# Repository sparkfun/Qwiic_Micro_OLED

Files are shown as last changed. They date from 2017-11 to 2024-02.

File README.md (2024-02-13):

SparkFun SparkFun Micro OLED Breakout (Qwiic)
========================================

SparkFun Micro OLED Breakout (Qwiic) (https://www.sparkfun.com/products/22495)

[*SparkFun Micro OLED Breakout (Qwiic) (LCD-22495)*](https://www.sparkfun.com/products/22495)

The SparkFun Qwiic Micro OLED Breakout is a Qwiic-enabled version of our popular Micro OLED display! The small monochrome, blue-on-black OLED screen presents incredibly clear images for your viewing pleasure. 

Repository Contents
-------------------

* **/Hardware** - Eagle design files (.brd, .sch)
* **/Libraries** - Libraries for use with the SparkFun Micro OLED Breakout (Qwiic)
* **/Production** - Production panel files (.brd)
* **/Software** - Related software for the SparkFun Micro OLED Breakout (Qwiic).

Documentation
--------------
* **[Micro OLED Breakout Library](https://github.com/sparkfun/SparkFun_Micro_OLED_Arduino_Library)** - Latest Arduino library for the Micro OLED Breakout.
* **[Qwiic Micro OLED Breakout Library](https://github.com/sparkfun/SparkFun_Qwiic_OLED_Arduino_Library)** - Alternative Arduino library for the Qwiic Micro OLED Breakout. This library is higher performance and handles memory better than the Micro OLED Arduino Library. This library also works with 2x other Qwiic OLEDs!!!
* **[SparkFun Fritzing Part](https://github.com/sparkfun/Fritzing_Parts/blob/main/products/22495_sfe_qwiic_micro_oled_breakout_top_view.fzpz)** - V11, top view
* **[SparkFun Fritzing Part](https://github.com/sparkfun/Fritzing_Parts/blob/main/products/14532_sfe_Qwiic_OLED_Breakout.fzpz)** - V10, bottom view
* **[Hookup Guide](https://learn.sparkfun.com/tutorials/qwiic-micro-oled-hookup-guide)** - Basic hookup guide for the SparkFun Micro OLED Breakout (Qwiic).

Product Versions
----------------
* [LCD-22495](https://www.sparkfun.com/products/22495) - SparkFun Qwiic Micro OLED Breakout, v11
* [LCD-14532](https://www.sparkfun.com/products/14532) - SparkFun Qwiic Micro OLED Breakout, v10
* [SPX-14269 (RETIRED)](https://www.sparkfun.com/products/14269) - SparkX Qwiic Micro OLED Breakout

License Information
-------------------

This product is _**open source**_! 

Please review the LICENSE.md file for license information. 

If you have any questions or concerns on licensing, please contact techsupport@sparkfun.com.

Distributed as-is; no warranty is given.

- Your friends at SparkFun.

_<COLLABORATION CREDIT>_

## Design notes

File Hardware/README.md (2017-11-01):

SparkFun <PRODUCT NAME> Design Files
=====================================

The .sch and .brd files hare are Eagle CAD schematic and PCB design files from SparkFun Electronics.
A freeware version of Eagle can be found [here](http://www.cadsoftusa.com/download-eagle/freeware/).

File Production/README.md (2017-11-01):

SparkFun <PRODUCT NAME> Production Files
=========================================

These are the production files SparkFun uses for printing PCBs.

License Information
-------------------
This product is open source! 

The hardware is released under [Creative Commons ShareAlike 4.0 International](https://creativecommons.org/licenses/by-sa/4.0/).

Please use, reuse, and modify these files as you see fit. Please maintain attribution to SparkFun Electronics and release anything derivative under the same license.

Distributed as-is; no warranty is given.

- Your friends at SparkFun.

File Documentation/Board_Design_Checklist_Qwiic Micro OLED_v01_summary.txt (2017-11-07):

1) Does this board adhere to the standard manufacturing process? (Kitting time, glue curing, humidor time, etc.) [NO]
comment: hot bar for screen

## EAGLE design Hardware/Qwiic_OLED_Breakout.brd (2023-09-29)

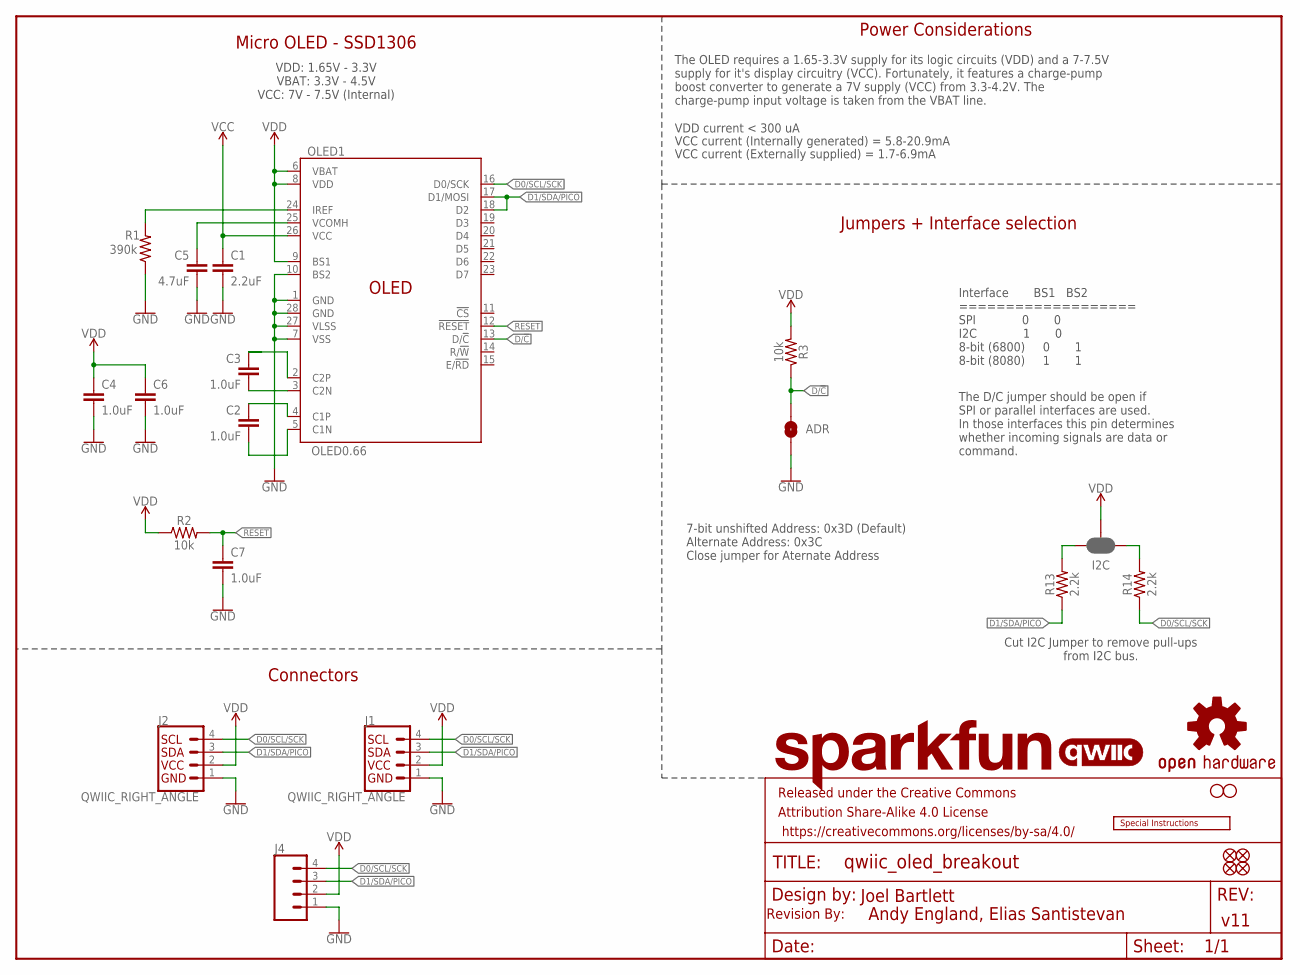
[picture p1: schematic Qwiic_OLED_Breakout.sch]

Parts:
ADR: JUMPER-SMT_2_NO_SILK; SMT-JUMPER_2_NO_SILK
C1: 2.2uF; 0805
C2, C3: 1.0uF; 0805
C4, C6, C7: 1.0uF; 0603
C5: 4.7uF; 1206
FID1, FID2, FID3, FID4: FIDUCIAL1X2; FIDUCIAL-1X2
FRAME1: FRAME-LETTER; CREATIVE_COMMONS
H1, H2: STAND-OFF
I2C: JUMPER-SMT_3_2-NC_PASTE_SILK; SMT-JUMPER_3_2-NC_PASTE_SILK
J1, J2: QWIIC_RIGHT_ANGLE; JST04_1MM_RA
J4: CONN_041X04_NO_SILK_NO_POP; 1X04_NO_SILK
LOGO2: SFE_LOGO_NAME.1_INCH; SFE_LOGO_NAME_.1
LOGO3: OSHW-LOGOS; OSHW-LOGO-S
LOGO5: QWIIC_LOGO_4MM; QWIIC_4MM
LOGO6: SPECIAL_INSTRUCTIONS-ORDERING; ORDERING_INSTRUCTIONS
OLED1: OLED0.66; OLED-0.66-64X48
R1: 390k; 0603
R2, R3: 10k; 0603
R13, R14: 2.2k; 0603

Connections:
C1P: C2.1, OLED1.4 (C1P)
C2N: C3.2, OLED1.3 (C2N)
D0/SCL/SCK: J1.4, J2.4, J4.4, OLED1.16 (D0/SCK), R14.1
D1/SDA/PICO: J1.3, J2.3, J4.3, OLED1.17 (D1/MOSI), OLED1.18 (D2), R13.1
D/!C!: ADR.2, OLED1.13 (D/!C!), R3.1
GND: ADR.1, C1.2, C4.2, C5.2, C6.2, C7.2, J1.1, J2.1, J4.1, OLED1.1 (GND), OLED1.7 (VSS), OLED1.10 (BS2), OLED1.27 (VLSS), OLED1.28 (GND), R1.1
IREF: OLED1.24 (IREF), R1.2
unnamed: C3.1, OLED1.2 (C2P)
unnamed: C2.2, OLED1.5 (C1N)
unnamed: I2C.3, R13.2
unnamed: I2C.1, R14.2
RESET: C7.1, OLED1.12 (!RESET!), R2.2
VCC: C1.1, OLED1.26 (VCC)
VCOMH: C5.1, OLED1.25 (VCOMH)
VDD: C4.1, C6.1, I2C.2, J1.2, J2.2, J4.2, OLED1.6 (VBAT), OLED1.8 (VDD), OLED1.9 (BS1), R2.1, R3.2

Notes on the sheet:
v11
VDD: 1.65V - 3.3V VBAT: 3.3V - 4.5V VCC: 7V - 7.5V (Internal)
VDD current < 300 uA
VCC current (Internally generated) = 5.8-20.9mA
VCC current (Externally supplied) = 1.7-6.9mA
Interface BS1 BS2 =================== SPI 0 0 I2C 1 0 8-bit (6800) 0 1 8-bit (8080) 1 1
Jumpers + Interface selection
7-bit unshifted Address: 0x3D (Default) Alternate Address: 0x3C Close jumper for Aternate Address
Power Considerations
The OLED requires a 1.65-3.3V supply for its logic circuits (VDD) and a 7-7.5V supply for it's display circuitry (VCC). Fortunately, it features a charge-pump boost converter to generate a 7V supply (VCC) from 3.3-4.2V. The charge-pump input voltage is taken from the VBAT line.
The D/C jumper should be open if SPI or parallel interfaces are used. In those interfaces this pin determines whether incoming signals are data or command.
Cut I2C Jumper to remove pull-ups from I2C bus.
Joel Bartlett
Andy England, Elias Santistevan
Connectors
Micro OLED - SSD1306
Revision By:

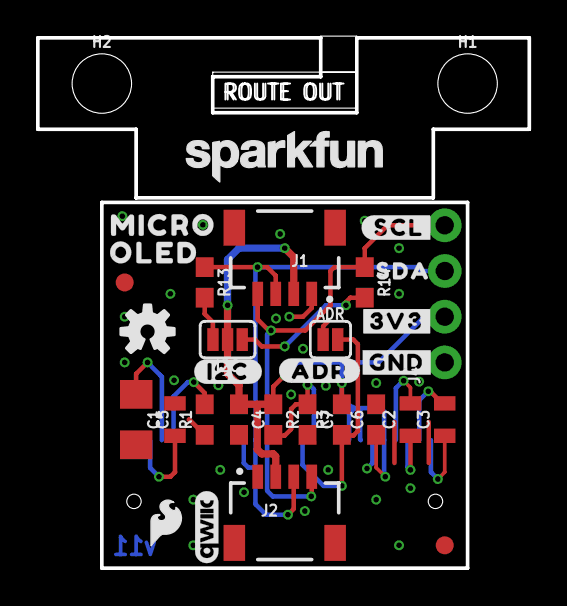
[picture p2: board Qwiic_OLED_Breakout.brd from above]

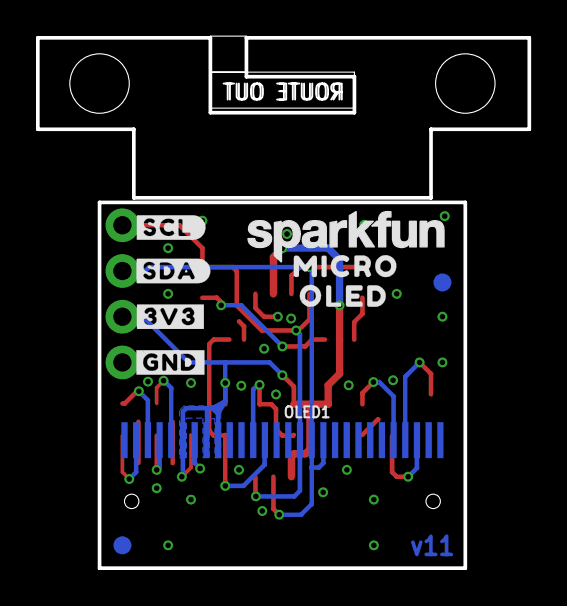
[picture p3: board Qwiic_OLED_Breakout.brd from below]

Board: 2 copper layers, 27.3 x 29.6 mm, 45 parts (10 on the bottom side), 15 nets.

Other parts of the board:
LOGO4: SFE_LOGO_NAME.1_INCH; SFE_LOGO_NAME_.1
U$1, U$13: MICRO593420
U$2, U$14: OLED593421
U$3: #ADR#5
U$4: #SCL#9
U$5, U$11: #3V3#1
U$6, U$12: #GND#0
U$7: SDA8
U$8: #I2C#1348
U$9: #SCL#8
U$10: #SDA#10
U$15: SFE_LOGO_FLAME_.1

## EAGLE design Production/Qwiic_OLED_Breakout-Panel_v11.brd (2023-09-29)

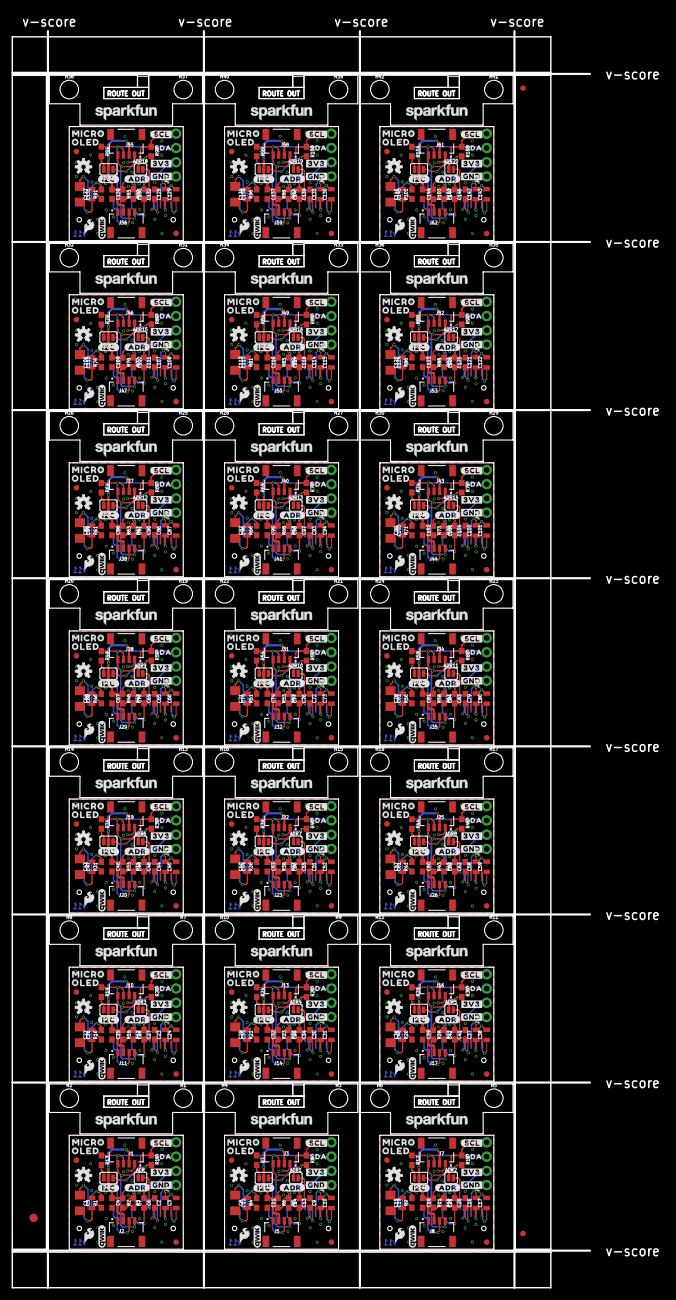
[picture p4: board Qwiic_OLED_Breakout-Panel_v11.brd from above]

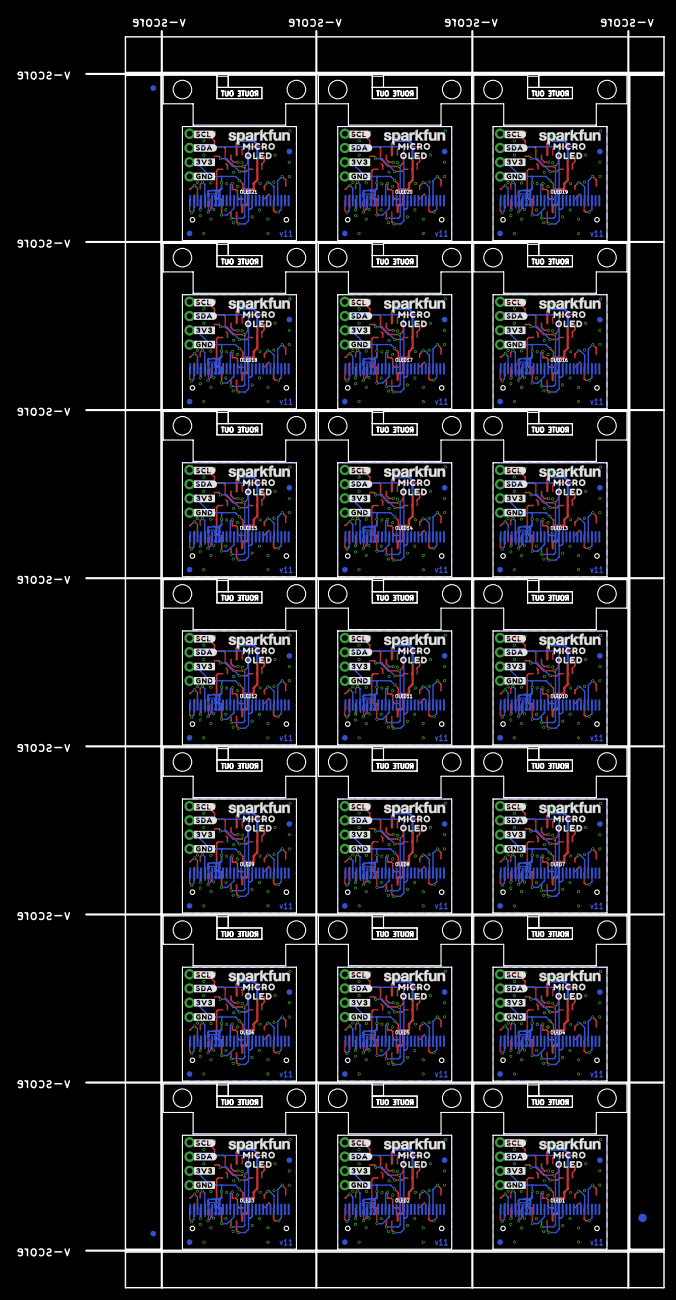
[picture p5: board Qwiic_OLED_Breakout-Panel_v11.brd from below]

Board: 2 copper layers, 103.0 x 224.0 mm, 909 parts (213 on the bottom side), 315 nets.

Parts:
ADR, ADR1, ADR2, ADR3, ADR4, ADR5, ADR6, ADR7, ADR8, ADR9, ADR10, ADR11, ADR12, ADR13, ADR14, ADR15, ADR16, ADR17, ADR18, ADR19, ADR20: JUMPER-SMT_2_NO_SILK; SMT-JUMPER_2_NO_SILK
C1, C8, C15, C22, C29, C36, C43, C50, C57, C64, C71, C78, C85, C92, C99, C106, C113, C120, C127, C134, C141: 2.2uF; 0805
C2, C3, C9, C10, C16, C17, C23, C24, C30, C31, C37, C38, C44, C45, C51, C52, C58, C59, C65, C66, C72, C73, C79, C80, C86, C87, C93, C94, C100, C101, C107, C108, C114, C115, C121, C122, C128, C129, C135, C136, C142, C143: 1.0uF; 0805
C4, C6, C7, C11, C13, C14, C18, C20, C21, C25, C27, C28, C32, C34, C35, C39, C41, C42, C46, C48, C49, C53, C55, C56, C60, C62, C63, C67, C69, C70, C74, C76, C77, C81, C83, C84, C88, C90, C91, C95, C97, C98, C102, C104, C105, C109, C111, C112, C116, C118, C119, C123, C125, C126, C130, C132, C133, C137, C139, C140, C144, C146, C147: 1.0uF; 0603
C5, C12, C19, C26, C33, C40, C47, C54, C61, C68, C75, C82, C89, C96, C103, C110, C117, C124, C131, C138, C145: 4.7uF; 1206
E$1, E$2, E$3, E$4: FIDUCIAL-1X2
E$5, E$6: FIDUCIAL-1.5X3
FID1, FID2, FID3, FID4, FID5, FID6, FID7, FID8, FID9, FID10, FID11, FID12, FID13, FID14, FID15, FID16, FID17, FID18, FID19, FID20, FID21, FID22, FID23, FID24, FID25, FID26, FID27, FID28, FID29, FID30, FID31, FID32, FID33, FID34, FID35, FID36, FID37, FID38, FID39, FID40, FID41, FID42, FID43, FID44, FID45, FID46, FID47, FID48, FID49, FID50, FID51, FID52, FID53, FID54, FID55, FID56, FID57, FID58, FID59, FID60, FID61, FID62, FID63, FID64, FID65, FID66, FID67, FID68, FID69, FID70, FID71, FID72, FID73, FID74, FID75, FID76, FID77, FID78, FID79, FID80, FID81, FID82, FID83, FID84: FIDUCIAL1X2; FIDUCIAL-1X2
H1, H2, H3, H4, H5, H6, H7, H8, H9, H10, H11, H12, H13, H14, H15, H16, H17, H18, H19, H20, H21, H22, H23, H24, H25, H26, H27, H28, H29, H30, H31, H32, H33, H34, H35, H36, H37, H38, H39, H40, H41, H42: STAND-OFF
I2C, I2C1, I2C2, I2C3, I2C4, I2C5, I2C6, I2C7, I2C8, I2C9, I2C10, I2C11, I2C12, I2C13, I2C14, I2C15, I2C16, I2C17, I2C18, I2C19, I2C20: JUMPER-SMT_3_2-NC_PASTE_SILK; SMT-JUMPER_3_2-NC_PASTE_SILK
J1, J2, J3, J5, J7, J8, J10, J11, J13, J14, J16, J17, J19, J20, J22, J23, J25, J26, J28, J29, J31, J32, J34, J35, J37, J38, J40, J41, J43, J44, J46, J47, J49, J50, J52, J53, J55, J56, J58, J59, J61, J62: QWIIC_RIGHT_ANGLE; JST04_1MM_RA
J4, J6, J9, J12, J15, J18, J21, J24, J27, J30, J33, J36, J39, J42, J45, J48, J51, J54, J57, J60, J63: 1X04_NO_SILK
LOGO1, LOGO3, LOGO9, LOGO13, LOGO17, LOGO21, LOGO25, LOGO29, LOGO33, LOGO37, LOGO41, LOGO45, LOGO49, LOGO53, LOGO57, LOGO61, LOGO65, LOGO69, LOGO73, LOGO77, LOGO81: OSHW-LOGOS; OSHW-LOGO-S
LOGO2, LOGO4, LOGO7, LOGO8, LOGO11, LOGO12, LOGO15, LOGO16, LOGO19, LOGO20, LOGO23, LOGO24, LOGO27, LOGO28, LOGO31, LOGO32, LOGO35, LOGO36, LOGO39, LOGO40, LOGO43, LOGO44, LOGO47, LOGO48, LOGO51, LOGO52, LOGO55, LOGO56, LOGO59, LOGO60, LOGO63, LOGO64, LOGO67, LOGO68, LOGO71, LOGO72, LOGO75, LOGO76, LOGO79, LOGO80, LOGO83, LOGO84: SFE_LOGO_NAME.1_INCH; SFE_LOGO_NAME_.1
LOGO5, LOGO6, LOGO10, LOGO14, LOGO18, LOGO22, LOGO26, LOGO30, LOGO34, LOGO38, LOGO42, LOGO46, LOGO50, LOGO54, LOGO58, LOGO62, LOGO66, LOGO70, LOGO74, LOGO78, LOGO82: QWIIC_LOGO_4MM; QWIIC_4MM
OLED1, OLED2, OLED3, OLED4, OLED5, OLED6, OLED7, OLED8, OLED9, OLED10, OLED11, OLED12, OLED13, OLED14, OLED15, OLED16, OLED17, OLED18, OLED19, OLED20, OLED21: OLED0.66; OLED-0.66-64X48
R1, R4, R9, R16, R21, R26, R31, R36, R41, R46, R51, R56, R61, R66, R71, R76, R81, R86, R91, R96, R101: 390k; 0603
R2, R3, R5, R6, R10, R11, R17, R18, R22, R23, R27, R28, R32, R33, R37, R38, R42, R43, R47, R48, R52, R53, R57, R58, R62, R63, R67, R68, R72, R73, R77, R78, R82, R83, R87, R88, R92, R93, R97, R98, R102, R103: 10k; 0603
R7, R8, R12, R13, R14, R15, R19, R20, R24, R25, R29, R30, R34, R35, R39, R40, R44, R45, R49, R50, R54, R55, R59, R60, R64, R65, R69, R70, R74, R75, R79, R80, R84, R85, R89, R90, R94, R95, R99, R100, R104, R105: 2.2k; 0603
U$1, U$13, U$16, U$28, U$31, U$43, U$46, U$58, U$61, U$73, U$76, U$88, U$91, U$103, U$106, U$118, U$121, U$133, U$136, U$148, U$151, U$163, U$166, U$178, U$181, U$193, U$196, U$208, U$211, U$223, U$226, U$238, U$241, U$253, U$256, U$268, U$271, U$283, U$286, U$298, U$301, U$313: MICRO593420
U$2, U$14, U$17, U$29, U$32, U$44, U$47, U$59, U$62, U$74, U$77, U$89, U$92, U$104, U$107, U$119, U$122, U$134, U$137, U$149, U$152, U$164, U$167, U$179, U$182, U$194, U$197, U$209, U$212, U$224, U$227, U$239, U$242, U$254, U$257, U$269, U$272, U$284, U$287, U$299, U$302, U$314: OLED593421
U$3, U$18, U$33, U$48, U$63, U$78, U$93, U$108, U$123, U$138, U$153, U$168, U$183, U$198, U$213, U$228, U$243, U$258, U$273, U$288, U$303: #ADR#5
U$4, U$19, U$34, U$49, U$64, U$79, U$94, U$109, U$124, U$139, U$154, U$169, U$184, U$199, U$214, U$229, U$244, U$259, U$274, U$289, U$304: #SCL#9
U$5, U$11, U$20, U$26, U$35, U$41, U$50, U$56, U$65, U$71, U$80, U$86, U$95, U$101, U$110, U$116, U$125, U$131, U$140, U$146, U$155, U$161, U$170, U$176, U$185, U$191, U$200, U$206, U$215, U$221, U$230, U$236, U$245, U$251, U$260, U$266, U$275, U$281, U$290, U$296, U$305, U$311: #3V3#1
U$6, U$12, U$21, U$27, U$36, U$42, U$51, U$57, U$66, U$72, U$81, U$87, U$96, U$102, U$111, U$117, U$126, U$132, U$141, U$147, U$156, U$162, U$171, U$177, U$186, U$192, U$201, U$207, U$216, U$222, U$231, U$237, U$246, U$252, U$261, U$267, U$276, U$282, U$291, U$297, U$306, U$312: #GND#0
U$7, U$22, U$37, U$52, U$67, U$82, U$97, U$112, U$127, U$142, U$157, U$172, U$187, U$202, U$217, U$232, U$247, U$262, U$277, U$292, U$307: SDA8
U$8, U$23, U$38, U$53, U$68, U$83, U$98, U$113, U$128, U$143, U$158, U$173, U$188, U$203, U$218, U$233, U$248, U$263, U$278, U$293, U$308: #I2C#1348
U$9, U$24, U$39, U$54, U$69, U$84, U$99, U$114, U$129, U$144, U$159, U$174, U$189, U$204, U$219, U$234, U$249, U$264, U$279, U$294, U$309: #SCL#8
U$10, U$25, U$40, U$55, U$70, U$85, U$100, U$115, U$130, U$145, U$160, U$175, U$190, U$205, U$220, U$235, U$250, U$265, U$280, U$295, U$310: #SDA#10
U$15, U$30, U$45, U$60, U$75, U$90, U$105, U$120, U$135, U$150, U$165, U$180, U$195, U$210, U$225, U$240, U$255, U$270, U$285, U$300, U$315: SFE_LOGO_FLAME_.1

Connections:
C1P: C2.1, OLED1.4
C1P1: C9.1, OLED2.4
C1P2: C16.1, OLED3.4
C1P3: C23.1, OLED4.4
C1P4: C30.1, OLED5.4
C1P5: C37.1, OLED6.4
C1P6: C44.1, OLED7.4
C1P7: C51.1, OLED8.4
C1P8: C58.1, OLED9.4
C1P9: C65.1, OLED10.4
C1P10: C72.1, OLED11.4
C1P11: C79.1, OLED12.4
C1P12: C86.1, OLED13.4
C1P13: C93.1, OLED14.4
C1P14: C100.1, OLED15.4
C1P15: C107.1, OLED16.4
C1P16: C114.1, OLED17.4
C1P17: C121.1, OLED18.4
C1P18: C128.1, OLED19.4
C1P19: C135.1, OLED20.4
C1P20: C142.1, OLED21.4
C2N: C3.2, OLED1.3
C2N1: C10.2, OLED2.3
C2N2: C17.2, OLED3.3
C2N3: C24.2, OLED4.3
C2N4: C31.2, OLED5.3
C2N5: C38.2, OLED6.3
C2N6: C45.2, OLED7.3
C2N7: C52.2, OLED8.3
C2N8: C59.2, OLED9.3
C2N9: C66.2, OLED10.3
C2N10: C73.2, OLED11.3
C2N11: C80.2, OLED12.3
C2N12: C87.2, OLED13.3
C2N13: C94.2, OLED14.3
C2N14: C101.2, OLED15.3
C2N15: C108.2, OLED16.3
C2N16: C115.2, OLED17.3
C2N17: C122.2, OLED18.3
C2N18: C129.2, OLED19.3
C2N19: C136.2, OLED20.3
C2N20: C143.2, OLED21.3
D0/SCL/SCK: J1.4, J2.4, J4.4, OLED1.16, R14.1
D0/SCL/SCK1: J3.4, J5.4, J6.4, OLED2.16, R8.1
D0/SCL/SCK2: J7.4, J8.4, J9.4, OLED3.16, R15.1
D0/SCL/SCK3: J10.4, J11.4, J12.4, OLED4.16, R20.1
D0/SCL/SCK4: J13.4, J14.4, J15.4, OLED5.16, R25.1
D0/SCL/SCK5: J16.4, J17.4, J18.4, OLED6.16, R30.1
D0/SCL/SCK6: J19.4, J20.4, J21.4, OLED7.16, R35.1
D0/SCL/SCK7: J22.4, J23.4, J24.4, OLED8.16, R40.1
D0/SCL/SCK8: J25.4, J26.4, J27.4, OLED9.16, R45.1
D0/SCL/SCK9: J28.4, J29.4, J30.4, OLED10.16, R50.1
D0/SCL/SCK10: J31.4, J32.4, J33.4, OLED11.16, R55.1
D0/SCL/SCK11: J34.4, J35.4, J36.4, OLED12.16, R60.1
D0/SCL/SCK12: J37.4, J38.4, J39.4, OLED13.16, R65.1
D0/SCL/SCK13: J40.4, J41.4, J42.4, OLED14.16, R70.1
D0/SCL/SCK14: J43.4, J44.4, J45.4, OLED15.16, R75.1
D0/SCL/SCK15: J46.4, J47.4, J48.4, OLED16.16, R80.1
D0/SCL/SCK16: J49.4, J50.4, J51.4, OLED17.16, R85.1
D0/SCL/SCK17: J52.4, J53.4, J54.4, OLED18.16, R90.1
D0/SCL/SCK18: J55.4, J56.4, J57.4, OLED19.16, R95.1
D0/SCL/SCK19: J58.4, J59.4, J60.4, OLED20.16, R100.1
D0/SCL/SCK20: J61.4, J62.4, J63.4, OLED21.16, R105.1
D1/SDA/PICO: J1.3, J2.3, J4.3, OLED1.17, OLED1.18, R13.1
D1/SDA/PICO1: J3.3, J5.3, J6.3, OLED2.17, OLED2.18, R7.1
D1/SDA/PICO2: J7.3, J8.3, J9.3, OLED3.17, OLED3.18, R12.1
D1/SDA/PICO3: J10.3, J11.3, J12.3, OLED4.17, OLED4.18, R19.1
D1/SDA/PICO4: J13.3, J14.3, J15.3, OLED5.17, OLED5.18, R24.1
D1/SDA/PICO5: J16.3, J17.3, J18.3, OLED6.17, OLED6.18, R29.1
D1/SDA/PICO6: J19.3, J20.3, J21.3, OLED7.17, OLED7.18, R34.1
D1/SDA/PICO7: J22.3, J23.3, J24.3, OLED8.17, OLED8.18, R39.1
D1/SDA/PICO8: J25.3, J26.3, J27.3, OLED9.17, OLED9.18, R44.1
D1/SDA/PICO9: J28.3, J29.3, J30.3, OLED10.17, OLED10.18, R49.1
D1/SDA/PICO10: J31.3, J32.3, J33.3, OLED11.17, OLED11.18, R54.1
D1/SDA/PICO11: J34.3, J35.3, J36.3, OLED12.17, OLED12.18, R59.1
D1/SDA/PICO12: J37.3, J38.3, J39.3, OLED13.17, OLED13.18, R64.1
D1/SDA/PICO13: J40.3, J41.3, J42.3, OLED14.17, OLED14.18, R69.1
D1/SDA/PICO14: J43.3, J44.3, J45.3, OLED15.17, OLED15.18, R74.1
D1/SDA/PICO15: J46.3, J47.3, J48.3, OLED16.17, OLED16.18, R79.1
D1/SDA/PICO16: J49.3, J50.3, J51.3, OLED17.17, OLED17.18, R84.1
D1/SDA/PICO17: J52.3, J53.3, J54.3, OLED18.17, OLED18.18, R89.1
D1/SDA/PICO18: J55.3, J56.3, J57.3, OLED19.17, OLED19.18, R94.1
D1/SDA/PICO19: J58.3, J59.3, J60.3, OLED20.17, OLED20.18, R99.1
D1/SDA/PICO20: J61.3, J62.3, J63.3, OLED21.17, OLED21.18, R104.1
D/!C!: ADR.2, OLED1.13, R3.1
D/!C!1: ADR1.2, OLED2.13, R5.1
D/!C!2: ADR2.2, OLED3.13, R10.1
D/!C!3: ADR3.2, OLED4.13, R17.1
D/!C!4: ADR4.2, OLED5.13, R22.1
D/!C!5: ADR5.2, OLED6.13, R27.1
D/!C!6: ADR6.2, OLED7.13, R32.1
D/!C!7: ADR7.2, OLED8.13, R37.1
D/!C!8: ADR8.2, OLED9.13, R42.1
D/!C!9: ADR9.2, OLED10.13, R47.1
D/!C!10: ADR10.2, OLED11.13, R52.1
D/!C!11: ADR11.2, OLED12.13, R57.1
D/!C!12: ADR12.2, OLED13.13, R62.1
D/!C!13: ADR13.2, OLED14.13, R67.1
D/!C!14: ADR14.2, OLED15.13, R72.1
D/!C!15: ADR15.2, OLED16.13, R77.1
D/!C!16: ADR16.2, OLED17.13, R82.1
D/!C!17: ADR17.2, OLED18.13, R87.1
D/!C!18: ADR18.2, OLED19.13, R92.1
D/!C!19: ADR19.2, OLED20.13, R97.1
D/!C!20: ADR20.2, OLED21.13, R102.1
GND: ADR.1, C1.2, C4.2, C5.2, C6.2, C7.2, J1.1, J2.1, J4.1, OLED1.1, OLED1.7, OLED1.10, OLED1.27, OLED1.28, R1.1
GND1: ADR1.1, C8.2, C11.2, C12.2, C13.2, C14.2, J3.1, J5.1, J6.1, OLED2.1, OLED2.7, OLED2.10, OLED2.27, OLED2.28, R4.1
GND2: ADR2.1, C15.2, C18.2, C19.2, C20.2, C21.2, J7.1, J8.1, J9.1, OLED3.1, OLED3.7, OLED3.10, OLED3.27, OLED3.28, R9.1
GND3: ADR3.1, C22.2, C25.2, C26.2, C27.2, C28.2, J10.1, J11.1, J12.1, OLED4.1, OLED4.7, OLED4.10, OLED4.27, OLED4.28, R16.1
GND4: ADR4.1, C29.2, C32.2, C33.2, C34.2, C35.2, J13.1, J14.1, J15.1, OLED5.1, OLED5.7, OLED5.10, OLED5.27, OLED5.28, R21.1
GND5: ADR5.1, C36.2, C39.2, C40.2, C41.2, C42.2, J16.1, J17.1, J18.1, OLED6.1, OLED6.7, OLED6.10, OLED6.27, OLED6.28, R26.1
GND6: ADR6.1, C43.2, C46.2, C47.2, C48.2, C49.2, J19.1, J20.1, J21.1, OLED7.1, OLED7.7, OLED7.10, OLED7.27, OLED7.28, R31.1
GND7: ADR7.1, C50.2, C53.2, C54.2, C55.2, C56.2, J22.1, J23.1, J24.1, OLED8.1, OLED8.7, OLED8.10, OLED8.27, OLED8.28, R36.1
GND8: ADR8.1, C57.2, C60.2, C61.2, C62.2, C63.2, J25.1, J26.1, J27.1, OLED9.1, OLED9.7, OLED9.10, OLED9.27, OLED9.28, R41.1
GND9: ADR9.1, C64.2, C67.2, C68.2, C69.2, C70.2, J28.1, J29.1, J30.1, OLED10.1, OLED10.7, OLED10.10, OLED10.27, OLED10.28, R46.1
GND10: ADR10.1, C71.2, C74.2, C75.2, C76.2, C77.2, J31.1, J32.1, J33.1, OLED11.1, OLED11.7, OLED11.10, OLED11.27, OLED11.28, R51.1
GND11: ADR11.1, C78.2, C81.2, C82.2, C83.2, C84.2, J34.1, J35.1, J36.1, OLED12.1, OLED12.7, OLED12.10, OLED12.27, OLED12.28, R56.1
GND12: ADR12.1, C85.2, C88.2, C89.2, C90.2, C91.2, J37.1, J38.1, J39.1, OLED13.1, OLED13.7, OLED13.10, OLED13.27, OLED13.28, R61.1
GND13: ADR13.1, C92.2, C95.2, C96.2, C97.2, C98.2, J40.1, J41.1, J42.1, OLED14.1, OLED14.7, OLED14.10, OLED14.27, OLED14.28, R66.1
GND14: ADR14.1, C99.2, C102.2, C103.2, C104.2, C105.2, J43.1, J44.1, J45.1, OLED15.1, OLED15.7, OLED15.10, OLED15.27, OLED15.28, R71.1
GND15: ADR15.1, C106.2, C109.2, C110.2, C111.2, C112.2, J46.1, J47.1, J48.1, OLED16.1, OLED16.7, OLED16.10, OLED16.27, OLED16.28, R76.1
GND16: ADR16.1, C113.2, C116.2, C117.2, C118.2, C119.2, J49.1, J50.1, J51.1, OLED17.1, OLED17.7, OLED17.10, OLED17.27, OLED17.28, R81.1
GND17: ADR17.1, C120.2, C123.2, C124.2, C125.2, C126.2, J52.1, J53.1, J54.1, OLED18.1, OLED18.7, OLED18.10, OLED18.27, OLED18.28, R86.1
GND18: ADR18.1, C127.2, C130.2, C131.2, C132.2, C133.2, J55.1, J56.1, J57.1, OLED19.1, OLED19.7, OLED19.10, OLED19.27, OLED19.28, R91.1
GND19: ADR19.1, C134.2, C137.2, C138.2, C139.2, C140.2, J58.1, J59.1, J60.1, OLED20.1, OLED20.7, OLED20.10, OLED20.27, OLED20.28, R96.1
GND20: ADR20.1, C141.2, C144.2, C145.2, C146.2, C147.2, J61.1, J62.1, J63.1, OLED21.1, OLED21.7, OLED21.10, OLED21.27, OLED21.28, R101.1
IREF: OLED1.24, R1.2
IREF1: OLED2.24, R4.2
IREF2: OLED3.24, R9.2
IREF3: OLED4.24, R16.2
IREF4: OLED5.24, R21.2
IREF5: OLED6.24, R26.2
IREF6: OLED7.24, R31.2
IREF7: OLED8.24, R36.2
IREF8: OLED9.24, R41.2
IREF9: OLED10.24, R46.2
IREF10: OLED11.24, R51.2
IREF11: OLED12.24, R56.2
IREF12: OLED13.24, R61.2
IREF13: OLED14.24, R66.2
IREF14: OLED15.24, R71.2
IREF15: OLED16.24, R76.2
IREF16: OLED17.24, R81.2
IREF17: OLED18.24, R86.2
IREF18: OLED19.24, R91.2
IREF19: OLED20.24, R96.2
IREF20: OLED21.24, R101.2
unnamed: C3.1, OLED1.2
unnamed: C2.2, OLED1.5
unnamed: I2C1.3, R7.2
unnamed: I2C.3, R13.2
unnamed: I2C.1, R14.2
unnamed: I2C1.1, R8.2
unnamed: C10.1, OLED2.2
unnamed: C9.2, OLED2.5
unnamed: I2C2.3, R12.2
unnamed: I2C2.1, R15.2
unnamed: C17.1, OLED3.2
unnamed: C16.2, OLED3.5
unnamed: I2C3.3, R19.2
unnamed: I2C3.1, R20.2
unnamed: C24.1, OLED4.2
unnamed: C23.2, OLED4.5
unnamed: I2C4.3, R24.2
unnamed: I2C4.1, R25.2
unnamed: C31.1, OLED5.2
unnamed: C30.2, OLED5.5
unnamed: I2C5.3, R29.2
unnamed: I2C5.1, R30.2
unnamed: C38.1, OLED6.2
unnamed: C37.2, OLED6.5
unnamed: I2C6.3, R34.2
unnamed: I2C6.1, R35.2
unnamed: C45.1, OLED7.2
unnamed: C44.2, OLED7.5
unnamed: I2C7.3, R39.2
unnamed: I2C7.1, R40.2
unnamed: C52.1, OLED8.2
unnamed: C51.2, OLED8.5
unnamed: I2C8.3, R44.2
unnamed: I2C8.1, R45.2
unnamed: C59.1, OLED9.2
unnamed: C58.2, OLED9.5
unnamed: I2C9.3, R49.2
unnamed: I2C9.1, R50.2
unnamed: C66.1, OLED10.2
unnamed: C65.2, OLED10.5
unnamed: I2C10.3, R54.2
unnamed: I2C10.1, R55.2
unnamed: C73.1, OLED11.2
unnamed: C72.2, OLED11.5
unnamed: I2C11.3, R59.2
unnamed: I2C11.1, R60.2
unnamed: C80.1, OLED12.2
unnamed: C79.2, OLED12.5
unnamed: I2C12.3, R64.2
unnamed: I2C12.1, R65.2
unnamed: C87.1, OLED13.2
unnamed: C86.2, OLED13.5
unnamed: I2C13.3, R69.2
unnamed: I2C13.1, R70.2
unnamed: C94.1, OLED14.2
unnamed: C93.2, OLED14.5
unnamed: I2C14.3, R74.2
unnamed: I2C14.1, R75.2
unnamed: C101.1, OLED15.2
unnamed: C100.2, OLED15.5
unnamed: I2C15.3, R79.2
unnamed: I2C15.1, R80.2
unnamed: C108.1, OLED16.2
unnamed: C107.2, OLED16.5
unnamed: I2C16.3, R84.2
unnamed: I2C16.1, R85.2
unnamed: C115.1, OLED17.2
unnamed: C114.2, OLED17.5
unnamed: I2C17.3, R89.2
unnamed: I2C17.1, R90.2
unnamed: C122.1, OLED18.2
unnamed: C121.2, OLED18.5
unnamed: I2C18.3, R94.2
unnamed: I2C18.1, R95.2
unnamed: C129.1, OLED19.2
unnamed: C128.2, OLED19.5
unnamed: I2C19.3, R99.2
unnamed: I2C19.1, R100.2
unnamed: C136.1, OLED20.2
unnamed: C135.2, OLED20.5
unnamed: I2C20.3, R104.2
unnamed: I2C20.1, R105.2
unnamed: C143.1, OLED21.2
unnamed: C142.2, OLED21.5
RESET: C7.1, OLED1.12, R2.2
RESET1: C14.1, OLED2.12, R6.2
RESET2: C21.1, OLED3.12, R11.2
RESET3: C28.1, OLED4.12, R18.2
RESET4: C35.1, OLED5.12, R23.2
RESET5: C42.1, OLED6.12, R28.2
RESET6: C49.1, OLED7.12, R33.2
RESET7: C56.1, OLED8.12, R38.2
RESET8: C63.1, OLED9.12, R43.2
RESET9: C70.1, OLED10.12, R48.2
RESET10: C77.1, OLED11.12, R53.2
RESET11: C84.1, OLED12.12, R58.2
RESET12: C91.1, OLED13.12, R63.2
RESET13: C98.1, OLED14.12, R68.2
RESET14: C105.1, OLED15.12, R73.2
RESET15: C112.1, OLED16.12, R78.2
RESET16: C119.1, OLED17.12, R83.2
RESET17: C126.1, OLED18.12, R88.2
RESET18: C133.1, OLED19.12, R93.2
RESET19: C140.1, OLED20.12, R98.2
RESET20: C147.1, OLED21.12, R103.2
VCC: C1.1, OLED1.26
VCC1: C8.1, OLED2.26
VCC2: C15.1, OLED3.26
VCC3: C22.1, OLED4.26
VCC4: C29.1, OLED5.26
VCC5: C36.1, OLED6.26
VCC6: C43.1, OLED7.26
VCC7: C50.1, OLED8.26
VCC8: C57.1, OLED9.26
VCC9: C64.1, OLED10.26
VCC10: C71.1, OLED11.26
VCC11: C78.1, OLED12.26
VCC12: C85.1, OLED13.26
VCC13: C92.1, OLED14.26
VCC14: C99.1, OLED15.26
VCC15: C106.1, OLED16.26
VCC16: C113.1, OLED17.26
VCC17: C120.1, OLED18.26
VCC18: C127.1, OLED19.26
VCC19: C134.1, OLED20.26
VCC20: C141.1, OLED21.26
VCOMH: C5.1, OLED1.25
VCOMH1: C12.1, OLED2.25
VCOMH2: C19.1, OLED3.25
VCOMH3: C26.1, OLED4.25
VCOMH4: C33.1, OLED5.25
VCOMH5: C40.1, OLED6.25
VCOMH6: C47.1, OLED7.25
VCOMH7: C54.1, OLED8.25
VCOMH8: C61.1, OLED9.25
VCOMH9: C68.1, OLED10.25
VCOMH10: C75.1, OLED11.25
VCOMH11: C82.1, OLED12.25
VCOMH12: C89.1, OLED13.25
VCOMH13: C96.1, OLED14.25
VCOMH14: C103.1, OLED15.25
VCOMH15: C110.1, OLED16.25
VCOMH16: C117.1, OLED17.25
VCOMH17: C124.1, OLED18.25
VCOMH18: C131.1, OLED19.25
VCOMH19: C138.1, OLED20.25
VCOMH20: C145.1, OLED21.25
VDD: C4.1, C6.1, I2C.2, J1.2, J2.2, J4.2, OLED1.6, OLED1.8, OLED1.9, R2.1, R3.2
VDD1: C11.1, C13.1, I2C1.2, J3.2, J5.2, J6.2, OLED2.6, OLED2.8, OLED2.9, R5.2, R6.1
VDD2: C18.1, C20.1, I2C2.2, J7.2, J8.2, J9.2, OLED3.6, OLED3.8, OLED3.9, R10.2, R11.1
VDD3: C25.1, C27.1, I2C3.2, J10.2, J11.2, J12.2, OLED4.6, OLED4.8, OLED4.9, R17.2, R18.1
VDD4: C32.1, C34.1, I2C4.2, J13.2, J14.2, J15.2, OLED5.6, OLED5.8, OLED5.9, R22.2, R23.1
VDD5: C39.1, C41.1, I2C5.2, J16.2, J17.2, J18.2, OLED6.6, OLED6.8, OLED6.9, R27.2, R28.1
VDD6: C46.1, C48.1, I2C6.2, J19.2, J20.2, J21.2, OLED7.6, OLED7.8, OLED7.9, R32.2, R33.1
VDD7: C53.1, C55.1, I2C7.2, J22.2, J23.2, J24.2, OLED8.6, OLED8.8, OLED8.9, R37.2, R38.1
VDD8: C60.1, C62.1, I2C8.2, J25.2, J26.2, J27.2, OLED9.6, OLED9.8, OLED9.9, R42.2, R43.1
VDD9: C67.1, C69.1, I2C9.2, J28.2, J29.2, J30.2, OLED10.6, OLED10.8, OLED10.9, R47.2, R48.1
VDD10: C74.1, C76.1, I2C10.2, J31.2, J32.2, J33.2, OLED11.6, OLED11.8, OLED11.9, R52.2, R53.1
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

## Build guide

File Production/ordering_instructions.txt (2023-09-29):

panel size, 97x224mm
PCB thickness, 1.6mm
number of layers, 2
soldermask color, Red
silkscreen color, White
oz copper, 1oz
finish, HASL lead free
stencils, top
pcs per panel, 21
min trace width, 0.2032mm / 0.0080in
min drill size, 0.3048mm / 0.0120in

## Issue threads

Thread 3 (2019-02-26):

Error with example `printTitle(String, int)` function

tnsolley, 2019-02-26:
Tried using a copy-pasted version of the example-function (see SFE page [here](https://learn.sparkfun.com/tutorials/qwiic-micro-oled-hookup-guide#examples)), I'm getting a compile error in Arduino IDE.
Arduino v. 1.8.8
Windows 10
Compiling for Arduino Nano.
See [here](https://github.com/sparkfun/SparkFun_SSD1320_OLED_Arduino_Library/issues/6) for context of the problem; using the Qwiic Micro OLED, `SFE_MicroOLED.h`, `SSD1320_OLED.h`...

Direct output of Arduino compiler;
....
```
H:\Dev\Cosplay_pictures\Legacy_Mando_SWEU\Helmet\sketch_jan21a\sketch_jan21a.ino: In function 'void loop()':

H:\Dev\Cosplay_pictures\Legacy_Mando_SWEU\Helmet\sketch_jan21a\sketch_jan21a.ino:92:6: note:   initializing argument 1 of 'void printTitle(String, int)'

 void printTitle(String title, int font)

      ^

exit status 1
Error compiling for board Arduino Nano.
```

santaimpersonator, 2021-06-16:
@tnsolley Is this still an issue?
It looks like you closed the other issue you filed: https://github.com/sparkfun/SparkFun_SSD1320_OLED_Arduino_Library/issues/6

santaimpersonator, 2021-07-01:
I'll close this for now. Feel free to reopen the issue if needed.

Closed 2021-07-01.

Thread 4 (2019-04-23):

Arduino Library Update

SFEMark, 2019-04-23:
The Arduino library linked here (https://github.com/sparkfun/Qwiic_Micro_OLED/tree/master/Libraries) is out of date. The Micro_OLED Arduino Library (https://github.com/sparkfun/SparkFun_Micro_OLED_Arduino_Library) has Qwiic examples added as well as some new fixes that help with compile issues for non-AVR boards. Can we get the library link merged with the Micro OLED Arduino Library?

nseidle, 2019-04-24:
Got it. I removed the old library from this repo. Best to keep software and hardware separate. I've started a separate issue in sparkle to fix the bad link in the tutorial (for Andy to fix).

Closed 2019-04-24.

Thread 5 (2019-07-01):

Example code won't compile with the ESP32 Thing Plus Board in Arduino

SFE-Pearce, 2019-07-01:
It gives a error for variables not declared in scope (A0,A1,A2).

santaimpersonator, 2019-07-12:
That is because there are no dedicated analog pins on the ESP32. You just need to re-declare the pins you are using for the joystick.

Closed 2019-07-12.

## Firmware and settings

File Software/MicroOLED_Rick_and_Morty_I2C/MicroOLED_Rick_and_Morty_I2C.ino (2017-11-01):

/******************************************************************************
 * MicroOLED_Demo.ino
 * SFE_MicroOLED Library Demo
 * Jim Lindblom @ SparkFun Electronics
 * Original Creation Date: October 27, 2014
 * 
 * This sketch uses the MicroOLED library to draw bitmaps to the OLED 
 * 
 * This example was modified for the Qwiic Micro OLED
 * Joel Bartlett
 * 04/12/17
 * 
 * Development environment specifics:
 *  Arduino 1.0.5
 *  Arduino Pro 3.3V
 *  Micro OLED Breakout v1.0
 * 
 * This code is beerware; if you see me (or any other SparkFun employee) at the
 * local, and you've found our code helpful, please buy us a round!
 * 
 * Distributed as-is; no warranty is given.
 ******************************************************************************/
#include <Wire.h>  // Include Wire if you're using I2C
#include <SFE_MicroOLED.h>  // Include the SFE_MicroOLED library
#include "bitmaps.h"

//////////////////////////
// MicroOLED Definition //
//////////////////////////
//The library assumes a reset pin is necessary. The Qwiic OLED has RST hard-wired, so pick an arbitrarty IO pin that is not being used
#define PIN_RESET 9  
//The DC_JUMPER is the I2C Address Select jumper. Set to 1 if the jumper is open (Default), or set to 0 if it's closed.
#define DC_JUMPER 1

//////////////////////////////////
// MicroOLED Object Declaration //
//////////////////////////////////
MicroOLED oled(PIN_RESET, DC_JUMPER);    // I2C declaration

void setup()
{
  delay(100);
  oled.begin();    // Initialize the OLED
  oled.clear(ALL); // Clear the display's internal memory
  oled.display();  // Display what's in the buffer (splashscreen)
  delay(1000);     // Delay 1000 ms
  oled.clear(PAGE); // Clear the buffer.
  
}
//---------------------------------------------------------------
void loop()
{
    drawRick();
    delay(5000);
    drawMorty();
    delay(5000);
}
//---------------------------------------------------------------
void drawRick()
{
    oled.clear(ALL);
    oled.clear(PAGE);
    oled.drawBitmap(rick);//Display Logo
    oled.display();
}
//---------------------------------------------------------------

void drawMorty()
{
    oled.clear(ALL);
    oled.clear(PAGE);
    oled.drawBitmap(morty);//Display Logo
    oled.display();
}

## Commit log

2017-11-02 getting rid of unnecessary files
    [Qwiic_OLED_Breakout_NO_T_Panel.GBL, Qwiic_OLED_Breakout_NO_T_Panel.GBO, Qwiic_OLED_Breakout_NO_T_Panel.GBP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]
2017-11-03 Pre-design Review
    [Qwiic_OLED_Breakout.brd]
2017-11-07 Post Checklist Changes
    [Board_Design_Checklist_Qwiic Micro OLED_v01.xls, Qwiic_OLED_Breakout.brd, Qwiic_OLED_Breakout.sch]
2017-12-04 Checklist issues fixed
    [Qwiic_OLED_Breakout.brd]
2017-12-04 fixed vscore
    [Qwiic_OLED_Breakout.brd]
2018-01-17 Squashed 'Libraries/Arduino/' content from commit 6ccbba3
    git-subtree-dir: Libraries/Arduino
    git-subtree-split: 6ccbba3deb1936ea34ce9319320bb4e321c3da03
2018-01-19 Delete README.md
    Removing since there is no Enclosure for the Qwiic Micro OLED
2018-01-19 cleaned repo
    [Board_Design_Checklist.xls, Board_Design_Checklist_Qwiic Micro OLED_V10.xls, OLED_Soldering_Jig.skp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]
2018-01-19 Update README.md
    link SparkX Qwiic Micro OLED Breakout board in the product versions.
2019-04-24 Remove old library files. Add link to current lib in readme.
2023-05-05 Expands the distance between the standoff 0.5" to adhere to our Qwiic standard
    * Updates silk
    * Organizes schematic
    * Adds ordering instructions
    * Adds additional measures and units for the measures
    [Qwiic_OLED_Breakout.brd, Qwiic_OLED_Breakout.sch]
2023-05-05 Updates jumper library
    [Qwiic_OLED_Breakout.brd, Qwiic_OLED_Breakout.sch]
2023-05-05 Updates D/C net
    [Qwiic_OLED_Breakout.brd, Qwiic_OLED_Breakout.sch]
2023-05-05 Fixes mounting hole spacing (derp)
    * Adds more measures
    * Changes pull up resistor values
    * Fixes some notes on ordering instructions
    * Adds more notes and silk
    * Connects some GND pour
    [Qwiic_OLED_Breakout.brd, Qwiic_OLED_Breakout.sch]
2023-05-08 Fixes some proportional text, cleans up some nets
    [Qwiic_OLED_Breakout.brd, Qwiic_OLED_Breakout.sch]
2023-05-08 Updates the isolate, replaces the main OLED part, adds some polygons
    [Qwiic_OLED_Breakout.brd, Qwiic_OLED_Breakout.sch]
2023-05-09 Moves Ordering Instructions
    * Updates notes in schematics
    [Qwiic_OLED_Breakout.brd, Qwiic_OLED_Breakout.sch]
2023-05-09 Adds a single via
    * Gets judicious with the text in the schematic
    [Qwiic_OLED_Breakout.brd, Qwiic_OLED_Breakout.sch]
2023-05-09 Approves DRC errors
    [Qwiic_OLED_Breakout.brd]
2023-05-09 Adds "Revised By: " to the Board file
    [Qwiic_OLED_Breakout.brd]
2023-05-09 Adds temporary production panel
    [Qwiic_OLED_Breakout-Panel.brd]
2023-05-10 Adds new panel after bringing the tabbed part to match the panel
    [Qwiic_OLED_Breakout-Panel.brd, Qwiic_OLED_Breakout.brd, Qwiic_OLED_Breakout.sch]
2023-05-10 Revised v11 panel to match v10 panel
    - Adjusted rail widths, board spacing, and fiducial locations to match v10 panel
    - Generated gerbers
    [Qwiic_OLED_Breakout-Panel.GBL, Qwiic_OLED_Breakout-Panel.GBO, Qwiic_OLED_Breakout-Panel.GBP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]
2023-05-11 Moves production files to the production folder, zips them together
    [13851-Qwiic_OLED_Breakout-Panel.v10.brd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]
2023-05-11 Removes erroneous file depth
    [Qwiic_OLED_Breakout-Panel.GBL, Qwiic_OLED_Breakout-Panel.GBO, Qwiic_OLED_Breakout-Panel.GBP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]

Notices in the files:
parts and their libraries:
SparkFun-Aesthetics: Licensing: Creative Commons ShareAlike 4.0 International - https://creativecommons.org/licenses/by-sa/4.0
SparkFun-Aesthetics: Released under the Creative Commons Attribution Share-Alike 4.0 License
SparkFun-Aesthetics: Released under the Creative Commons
